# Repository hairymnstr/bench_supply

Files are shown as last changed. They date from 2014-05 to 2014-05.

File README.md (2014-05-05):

Bench Supply
============

This is a fairly basic bench power supply project I'm working on.  It started
off as a one-off design with all through-hole and stripboard construction but
I'm probably going to get the channels at least done on a PCB to make it more
robust.

All done in KiCAD so far, there will be some software for driving the current
and voltage displays later on.  There are two projects so far, the control
board which is a one-off that does non channel specific things like output on
off control, and a channel design which I'm using twice to provide two
separate floating supply rails.

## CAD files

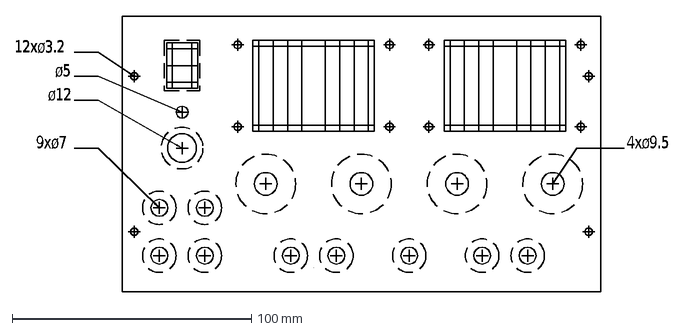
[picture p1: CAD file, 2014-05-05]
sch/channel/front_panel.dxf
12xø3.2
9xø7
ø12
ø5
4xø9.5

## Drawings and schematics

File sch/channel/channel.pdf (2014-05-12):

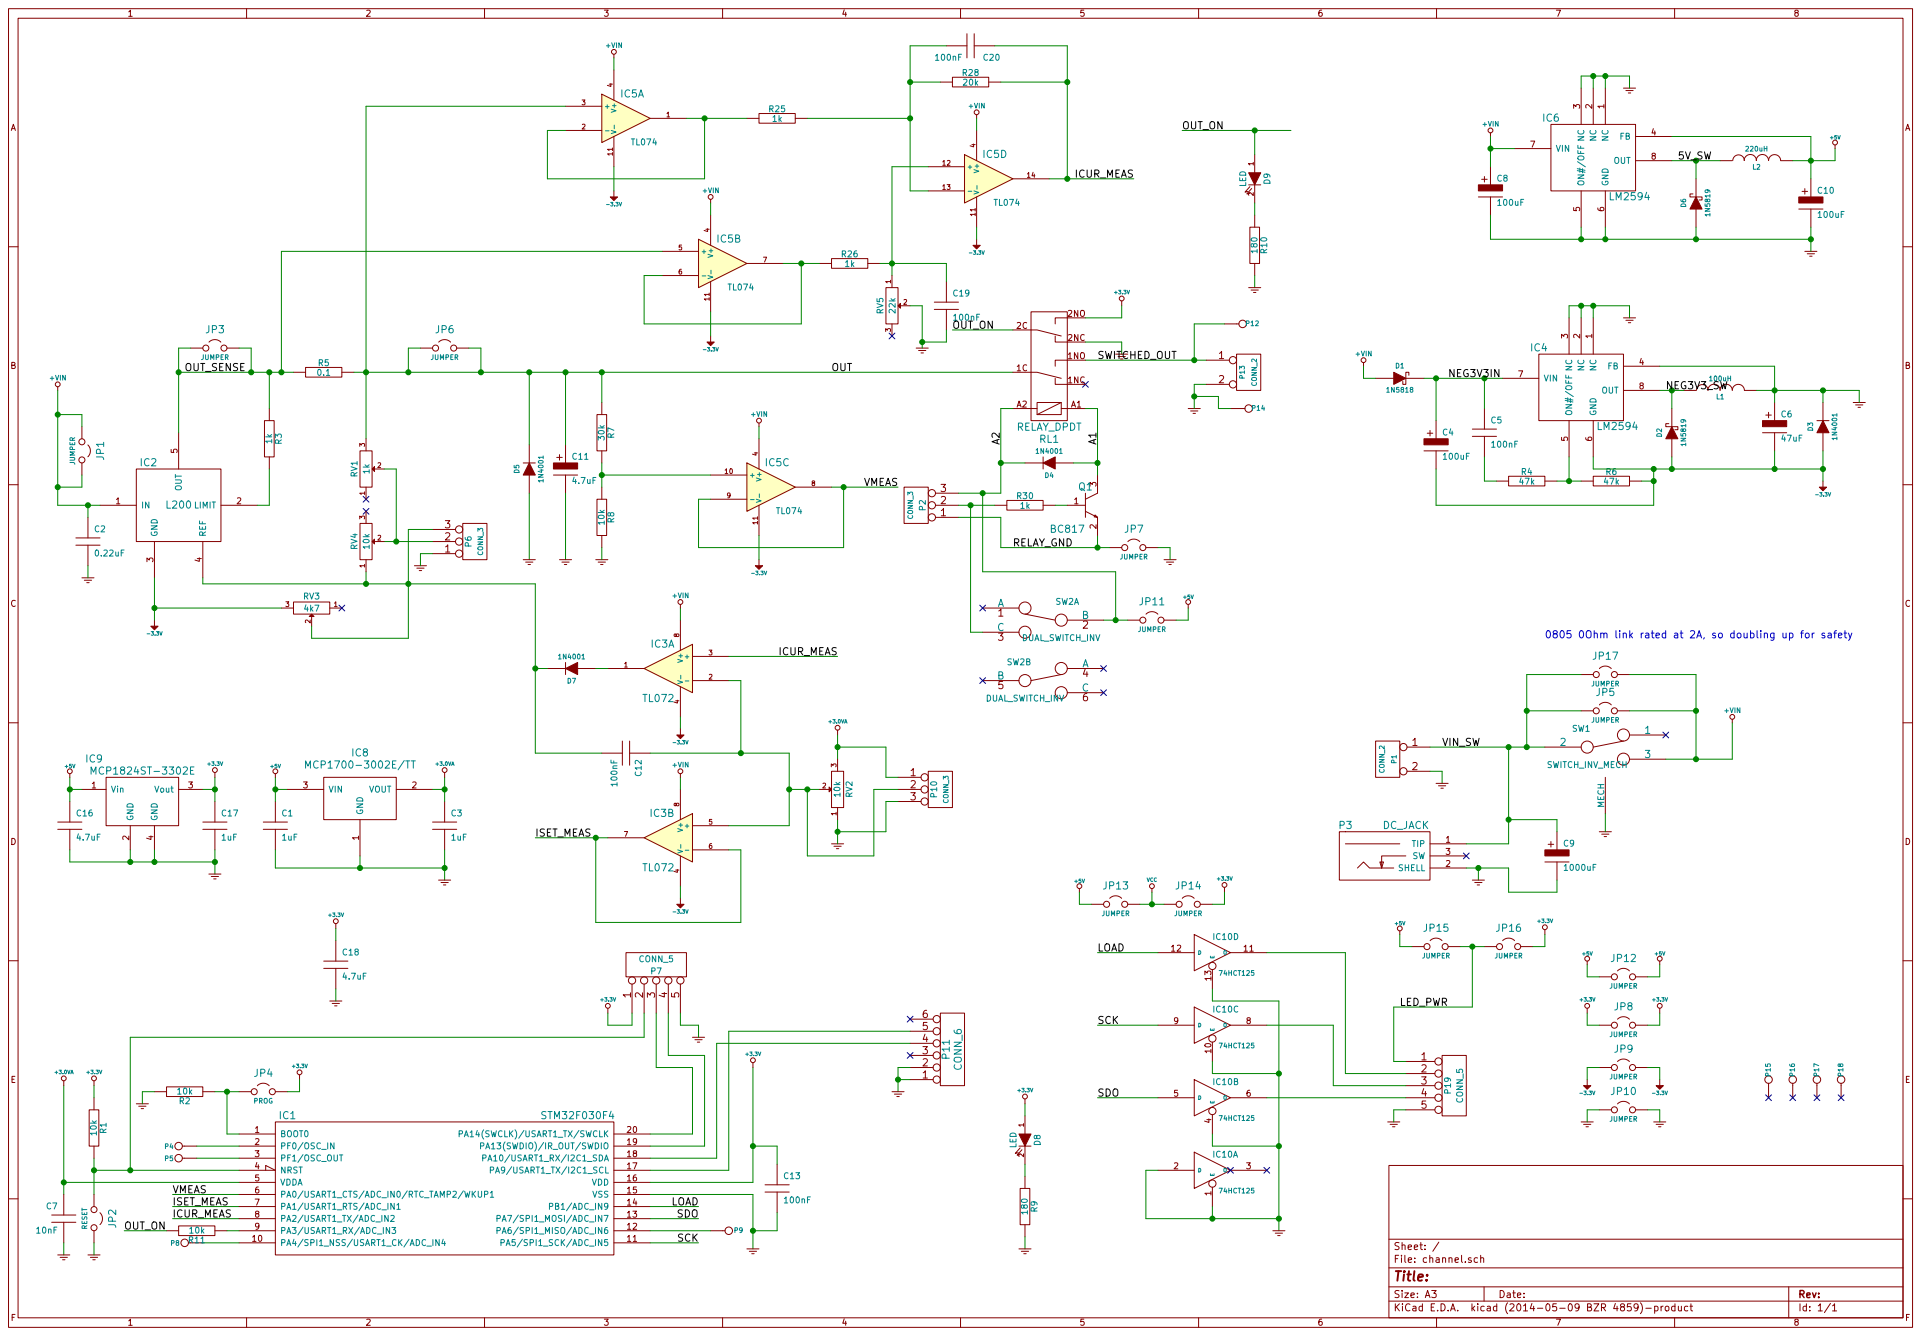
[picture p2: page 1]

JUMPER 0805 0Ohm link rated at 2A, so doubling up for safety

Id: 1/1 Title: File: channel.sch Sheet: / VMEAS

ISET_MEAS | | LOAD
ICUR_MEAS | SDO

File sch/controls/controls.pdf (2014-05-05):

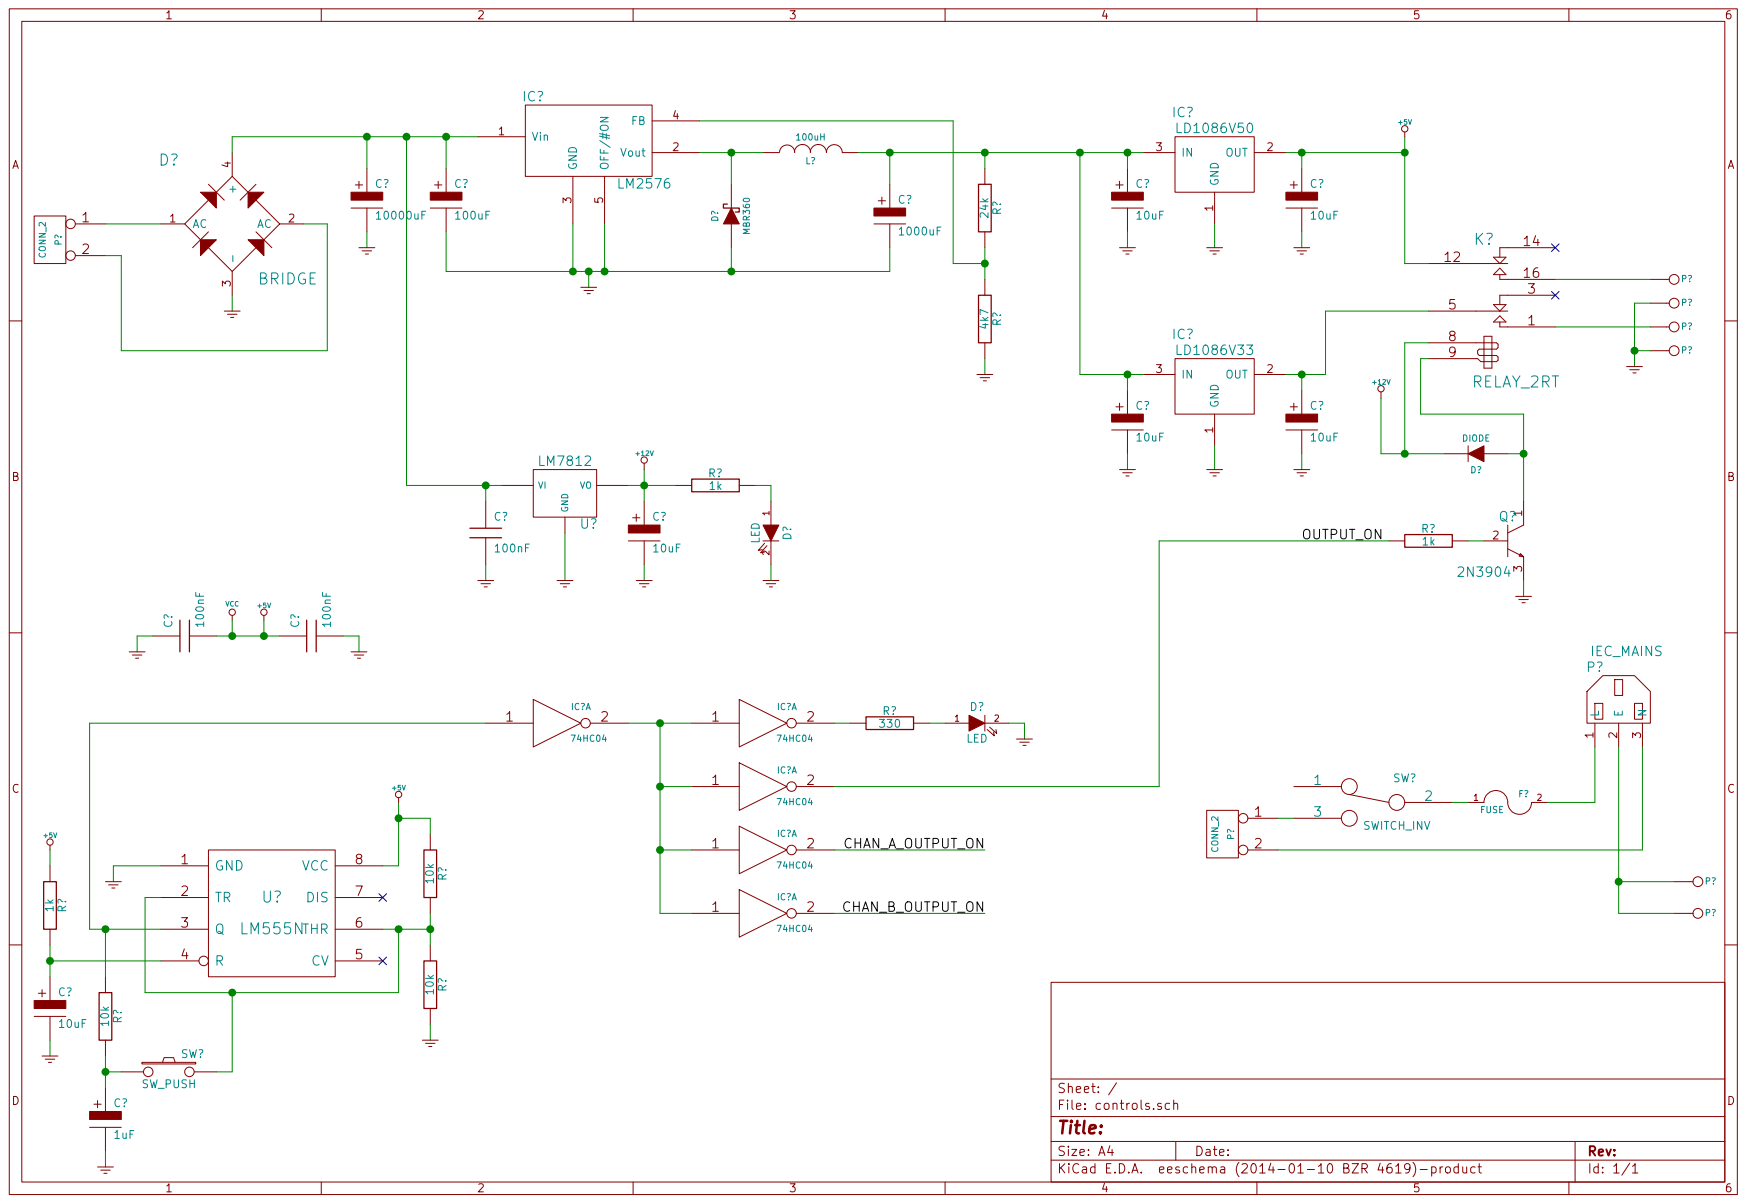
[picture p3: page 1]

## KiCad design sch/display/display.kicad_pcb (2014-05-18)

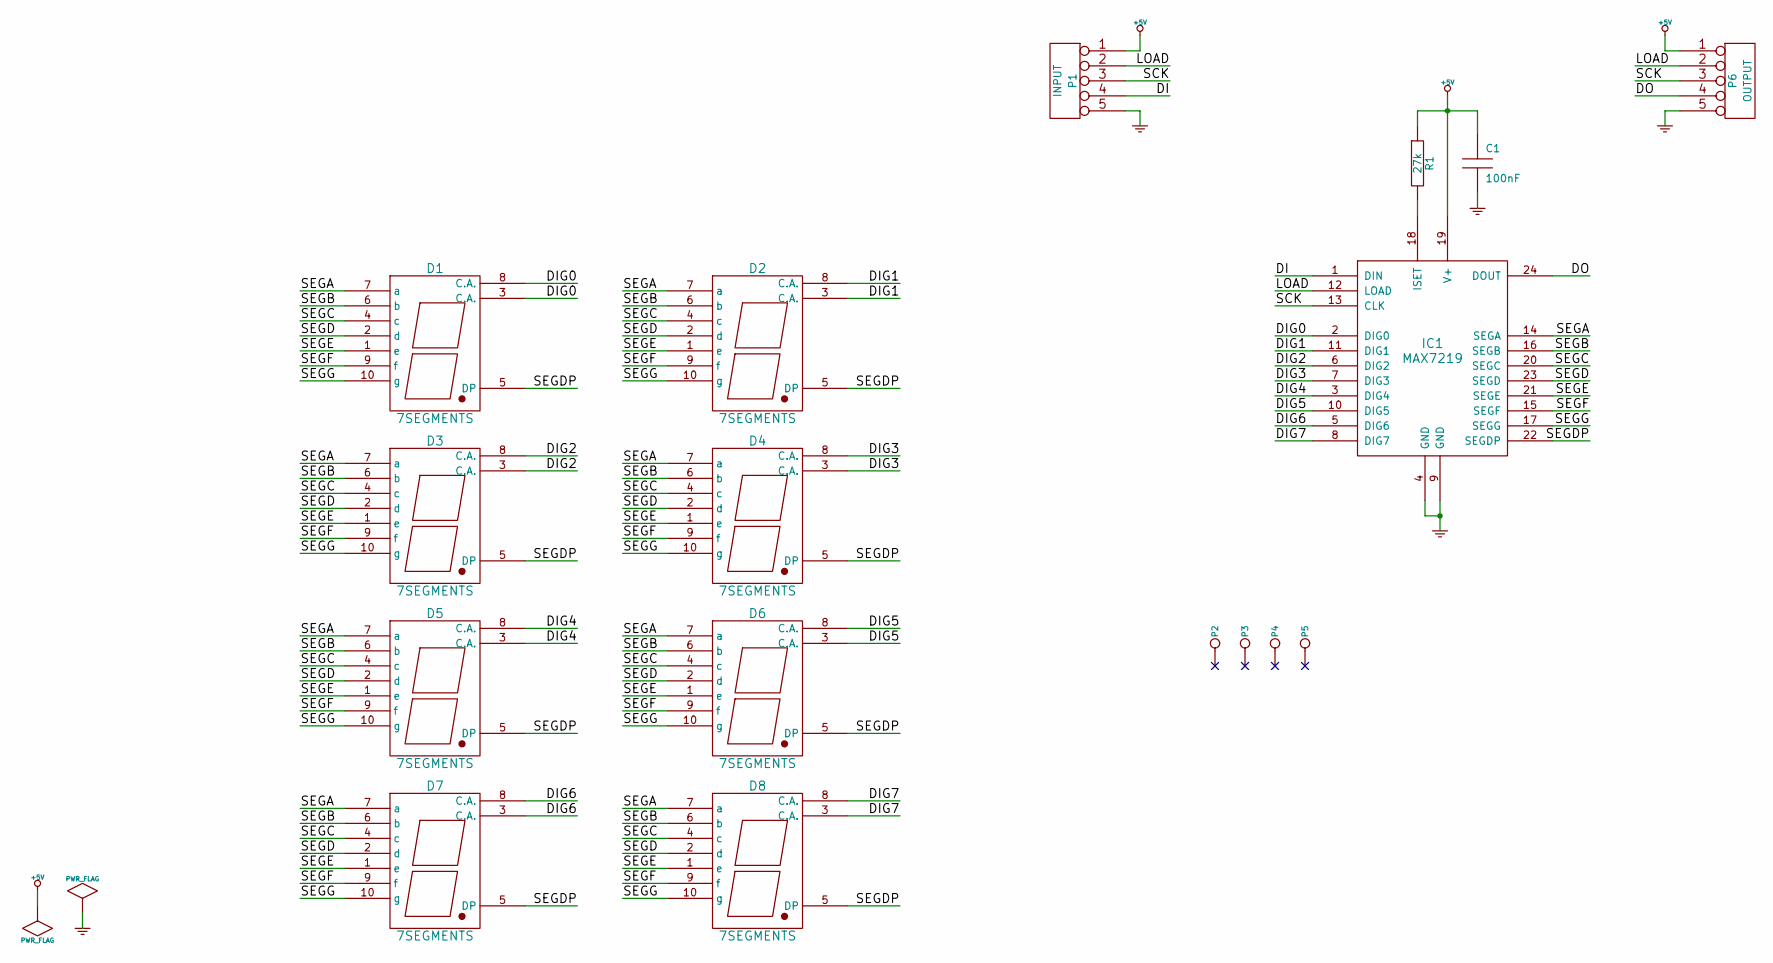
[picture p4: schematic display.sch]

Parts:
C1: 100nF
D1, D2, D3, D4, D5, D6, D7, D8: 7SEGMENTS
IC1: MAX7219
P1: INPUT
P2, P3, P4, P5: CONN_1
P6: OUTPUT
R1: 27k

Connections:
+5V: C1.1, IC1.19 (V+), P1.1, P6.1, R1.1
/DI: IC1.1 (DIN), P1.4
/DIG0: D1.3 (C.A.), D1.8 (C.A.), IC1.2 (DIG0)
/DIG1: D2.3 (C.A.), D2.8 (C.A.), IC1.11 (DIG1)
/DIG2: D3.3 (C.A.), D3.8 (C.A.), IC1.6 (DIG2)
/DIG3: D4.3 (C.A.), D4.8 (C.A.), IC1.7 (DIG3)
/DIG4: D5.3 (C.A.), D5.8 (C.A.), IC1.3 (DIG4)
/DIG5: D6.3 (C.A.), D6.8 (C.A.), IC1.10 (DIG5)
/DIG6: D7.3 (C.A.), D7.8 (C.A.), IC1.5 (DIG6)
/DIG7: D8.3 (C.A.), D8.8 (C.A.), IC1.8 (DIG7)
/DO: IC1.24 (DOUT), P6.4
/LOAD: IC1.12 (LOAD), P1.2, P6.2
/SCK: IC1.13 (CLK), P1.3, P6.3
/SEGA: D1.7 (a), D2.7 (a), D3.7 (a), D4.7 (a), D5.7 (a), D6.7 (a), D7.7 (a), D8.7 (a), IC1.14 (SEGA)
/SEGB: D1.6 (b), D2.6 (b), D3.6 (b), D4.6 (b), D5.6 (b), D6.6 (b), D7.6 (b), D8.6 (b), IC1.16 (SEGB)
/SEGC: D1.4 (c), D2.4 (c), D3.4 (c), D4.4 (c), D5.4 (c), D6.4 (c), D7.4 (c), D8.4 (c), IC1.20 (SEGC)
/SEGD: D1.2 (d), D2.2 (d), D3.2 (d), D4.2 (d), D5.2 (d), D6.2 (d), D7.2 (d), D8.2 (d), IC1.23 (SEGD)
/SEGDP: D1.5 (DP), D2.5 (DP), D3.5 (DP), D4.5 (DP), D5.5 (DP), D6.5 (DP), D7.5 (DP), D8.5 (DP), IC1.22 (SEGDP)
/SEGE: D1.1 (e), D2.1 (e), D3.1 (e), D4.1 (e), D5.1 (e), D6.1 (e), D7.1 (e), D8.1 (e), IC1.21 (SEGE)
/SEGF: D1.9 (f), D2.9 (f), D3.9 (f), D4.9 (f), D5.9 (f), D6.9 (f), D7.9 (f), D8.9 (f), IC1.15 (SEGF)
/SEGG: D1.10 (g), D2.10 (g), D3.10 (g), D4.10 (g), D5.10 (g), D6.10 (g), D7.10 (g), D8.10 (g), IC1.17 (SEGG)
GND: C1.2, IC1.4 (GND), IC1.9 (GND), P1.5, P6.5
unnamed: IC1.18 (ISET), R1.2

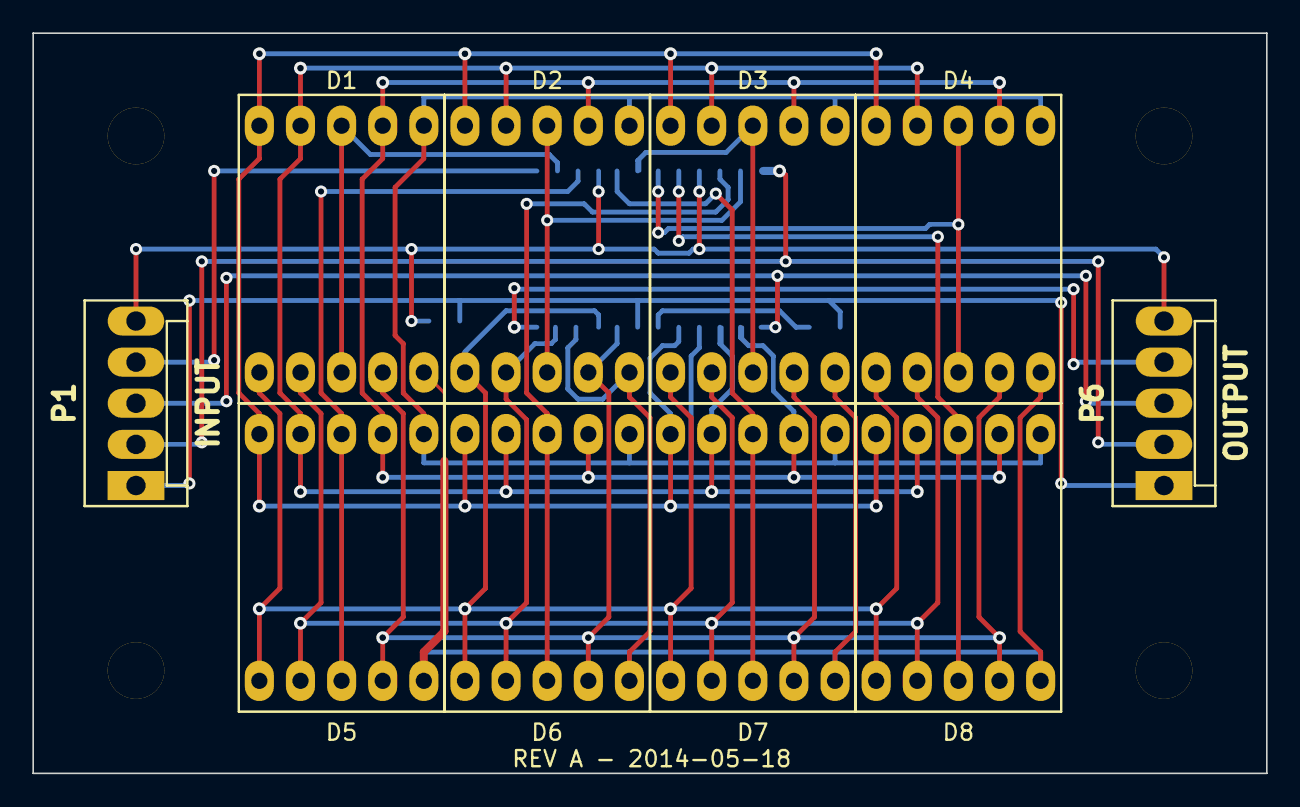
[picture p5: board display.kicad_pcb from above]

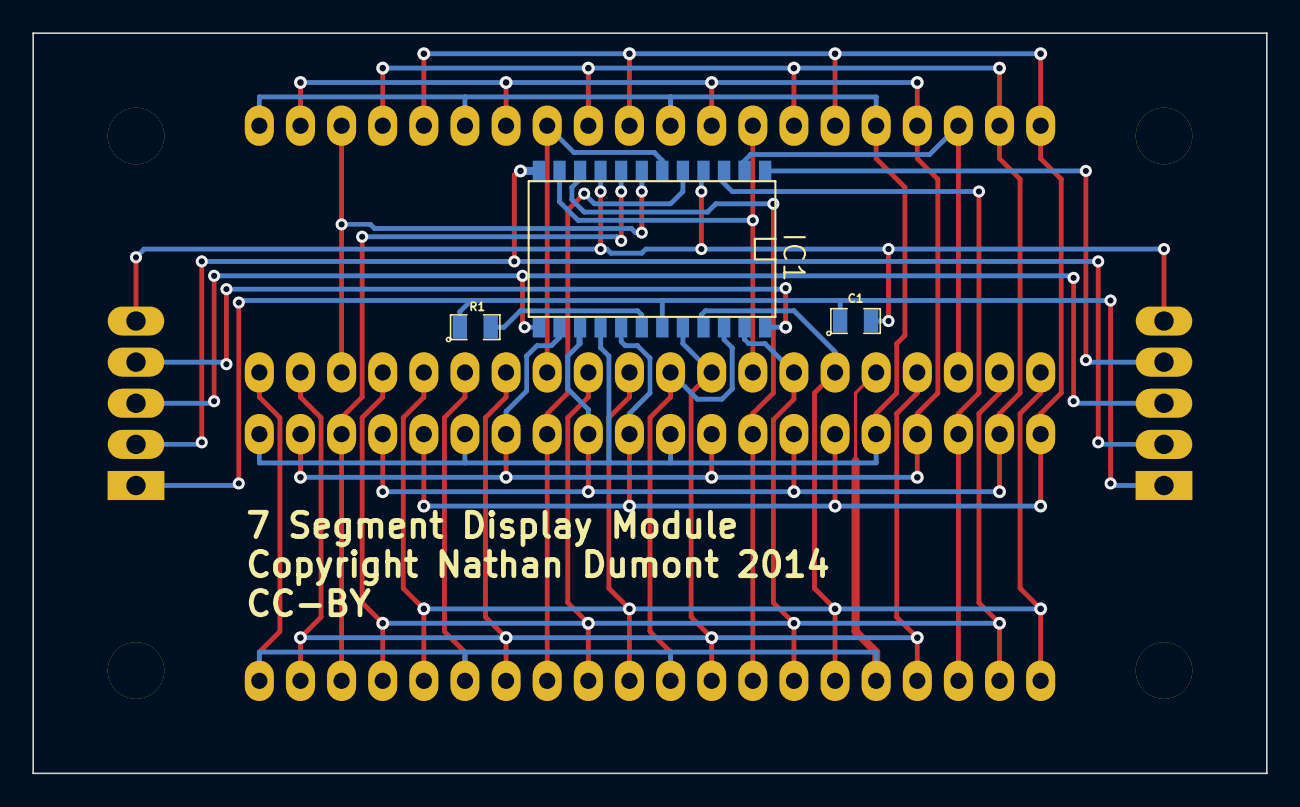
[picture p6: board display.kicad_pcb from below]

Board: 2 copper layers, 76.2 x 45.7 mm, 17 parts (3 on the bottom side), 23 nets.

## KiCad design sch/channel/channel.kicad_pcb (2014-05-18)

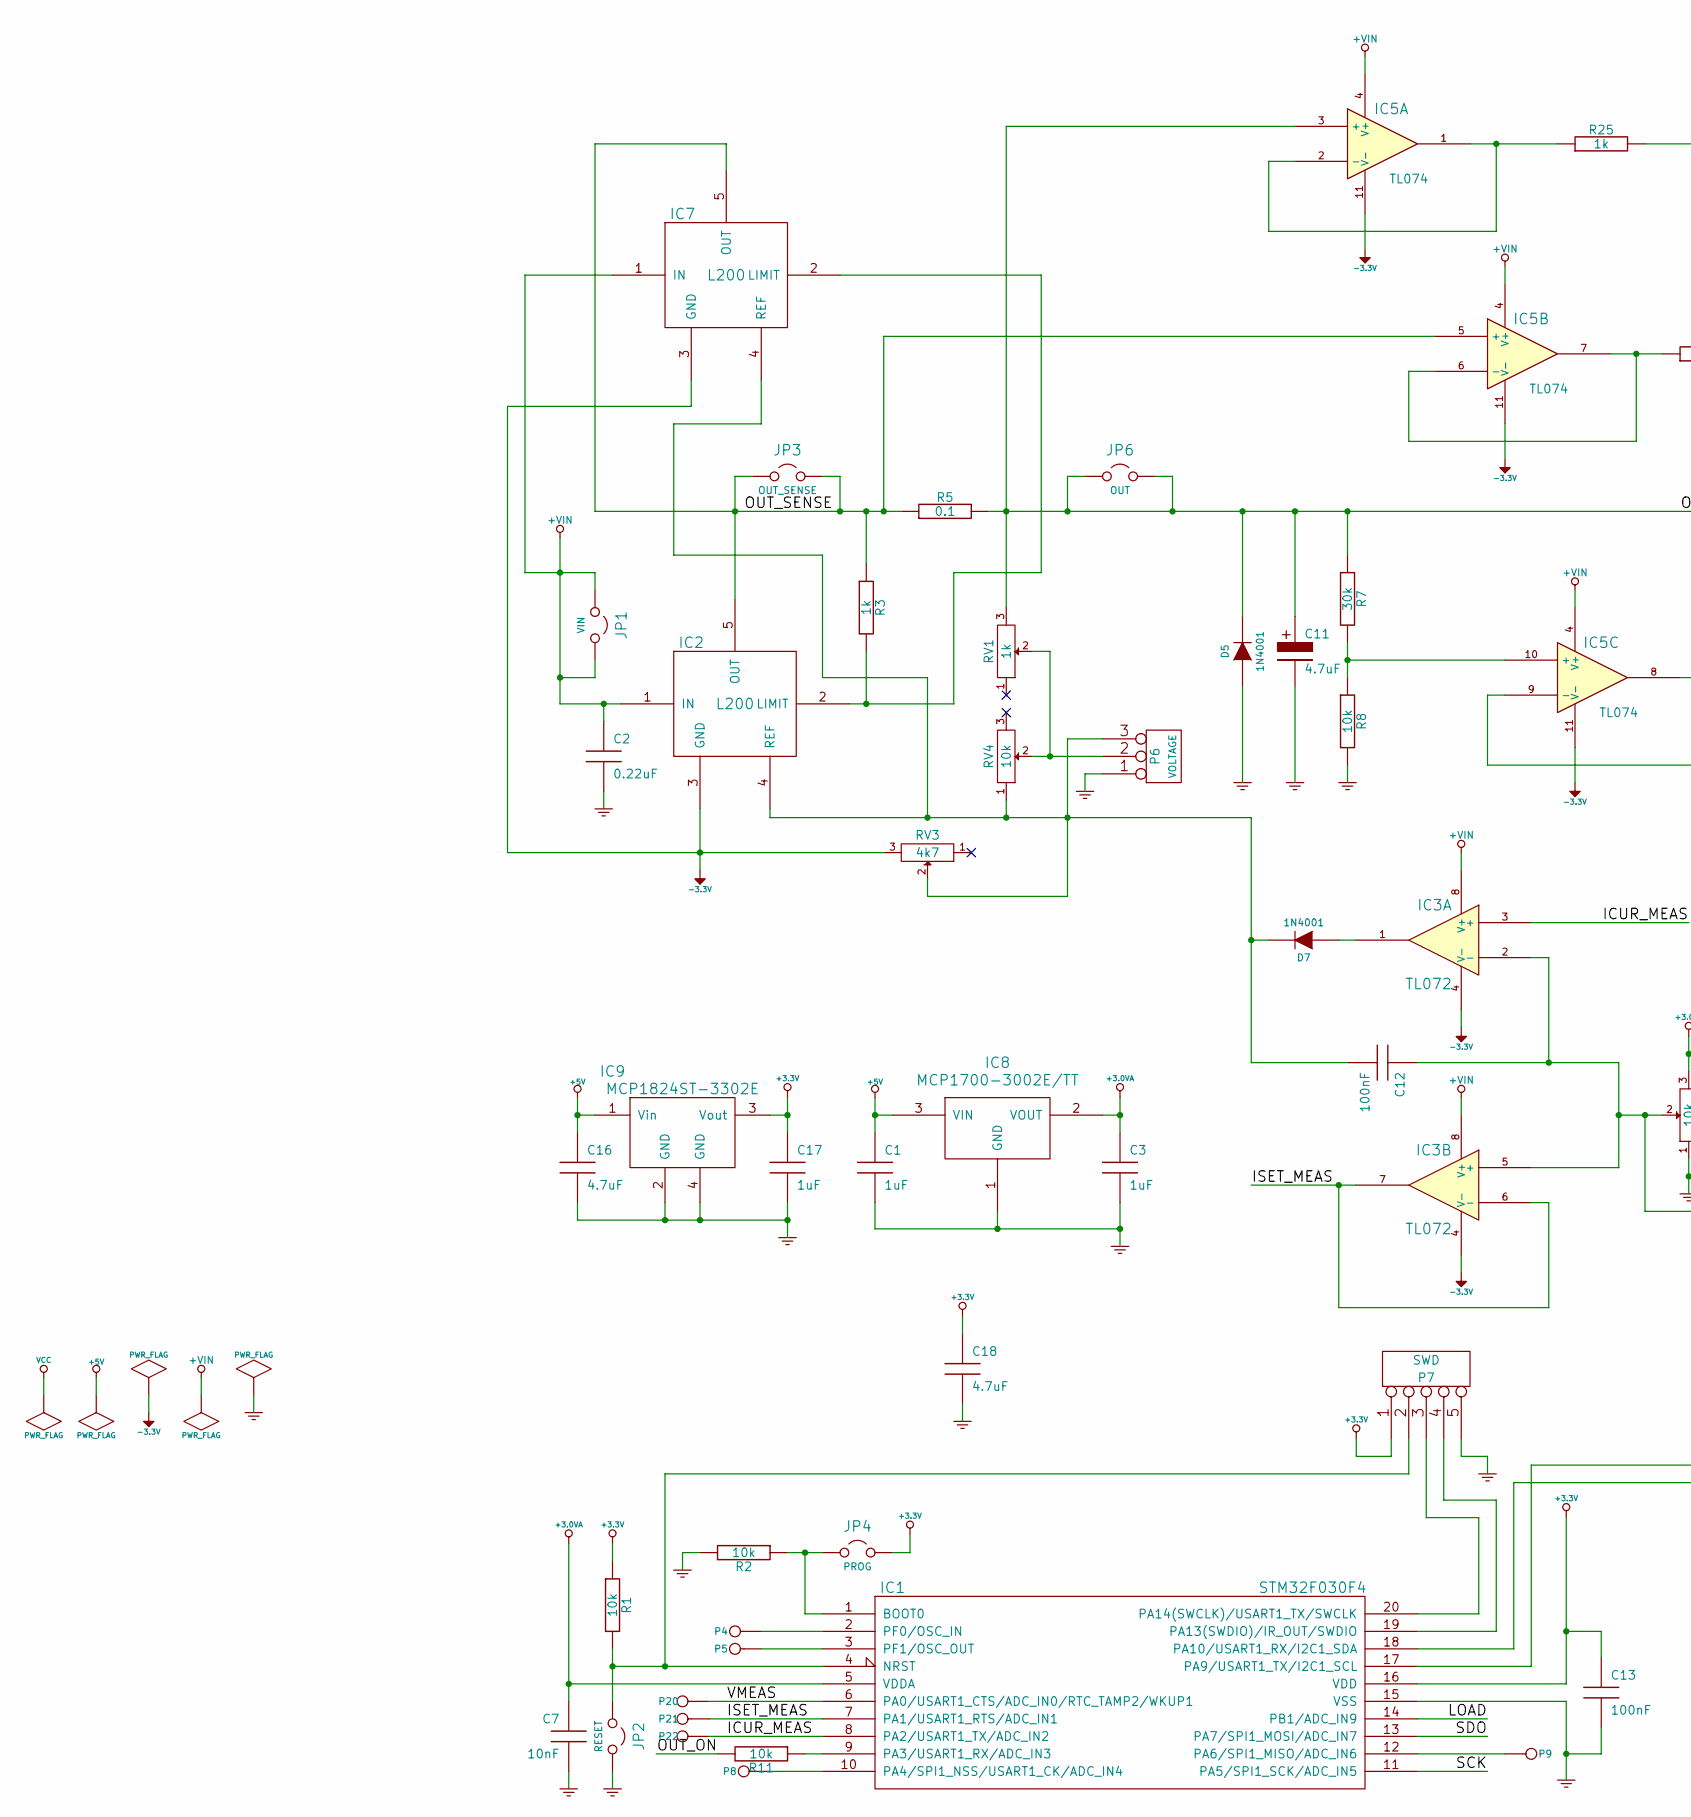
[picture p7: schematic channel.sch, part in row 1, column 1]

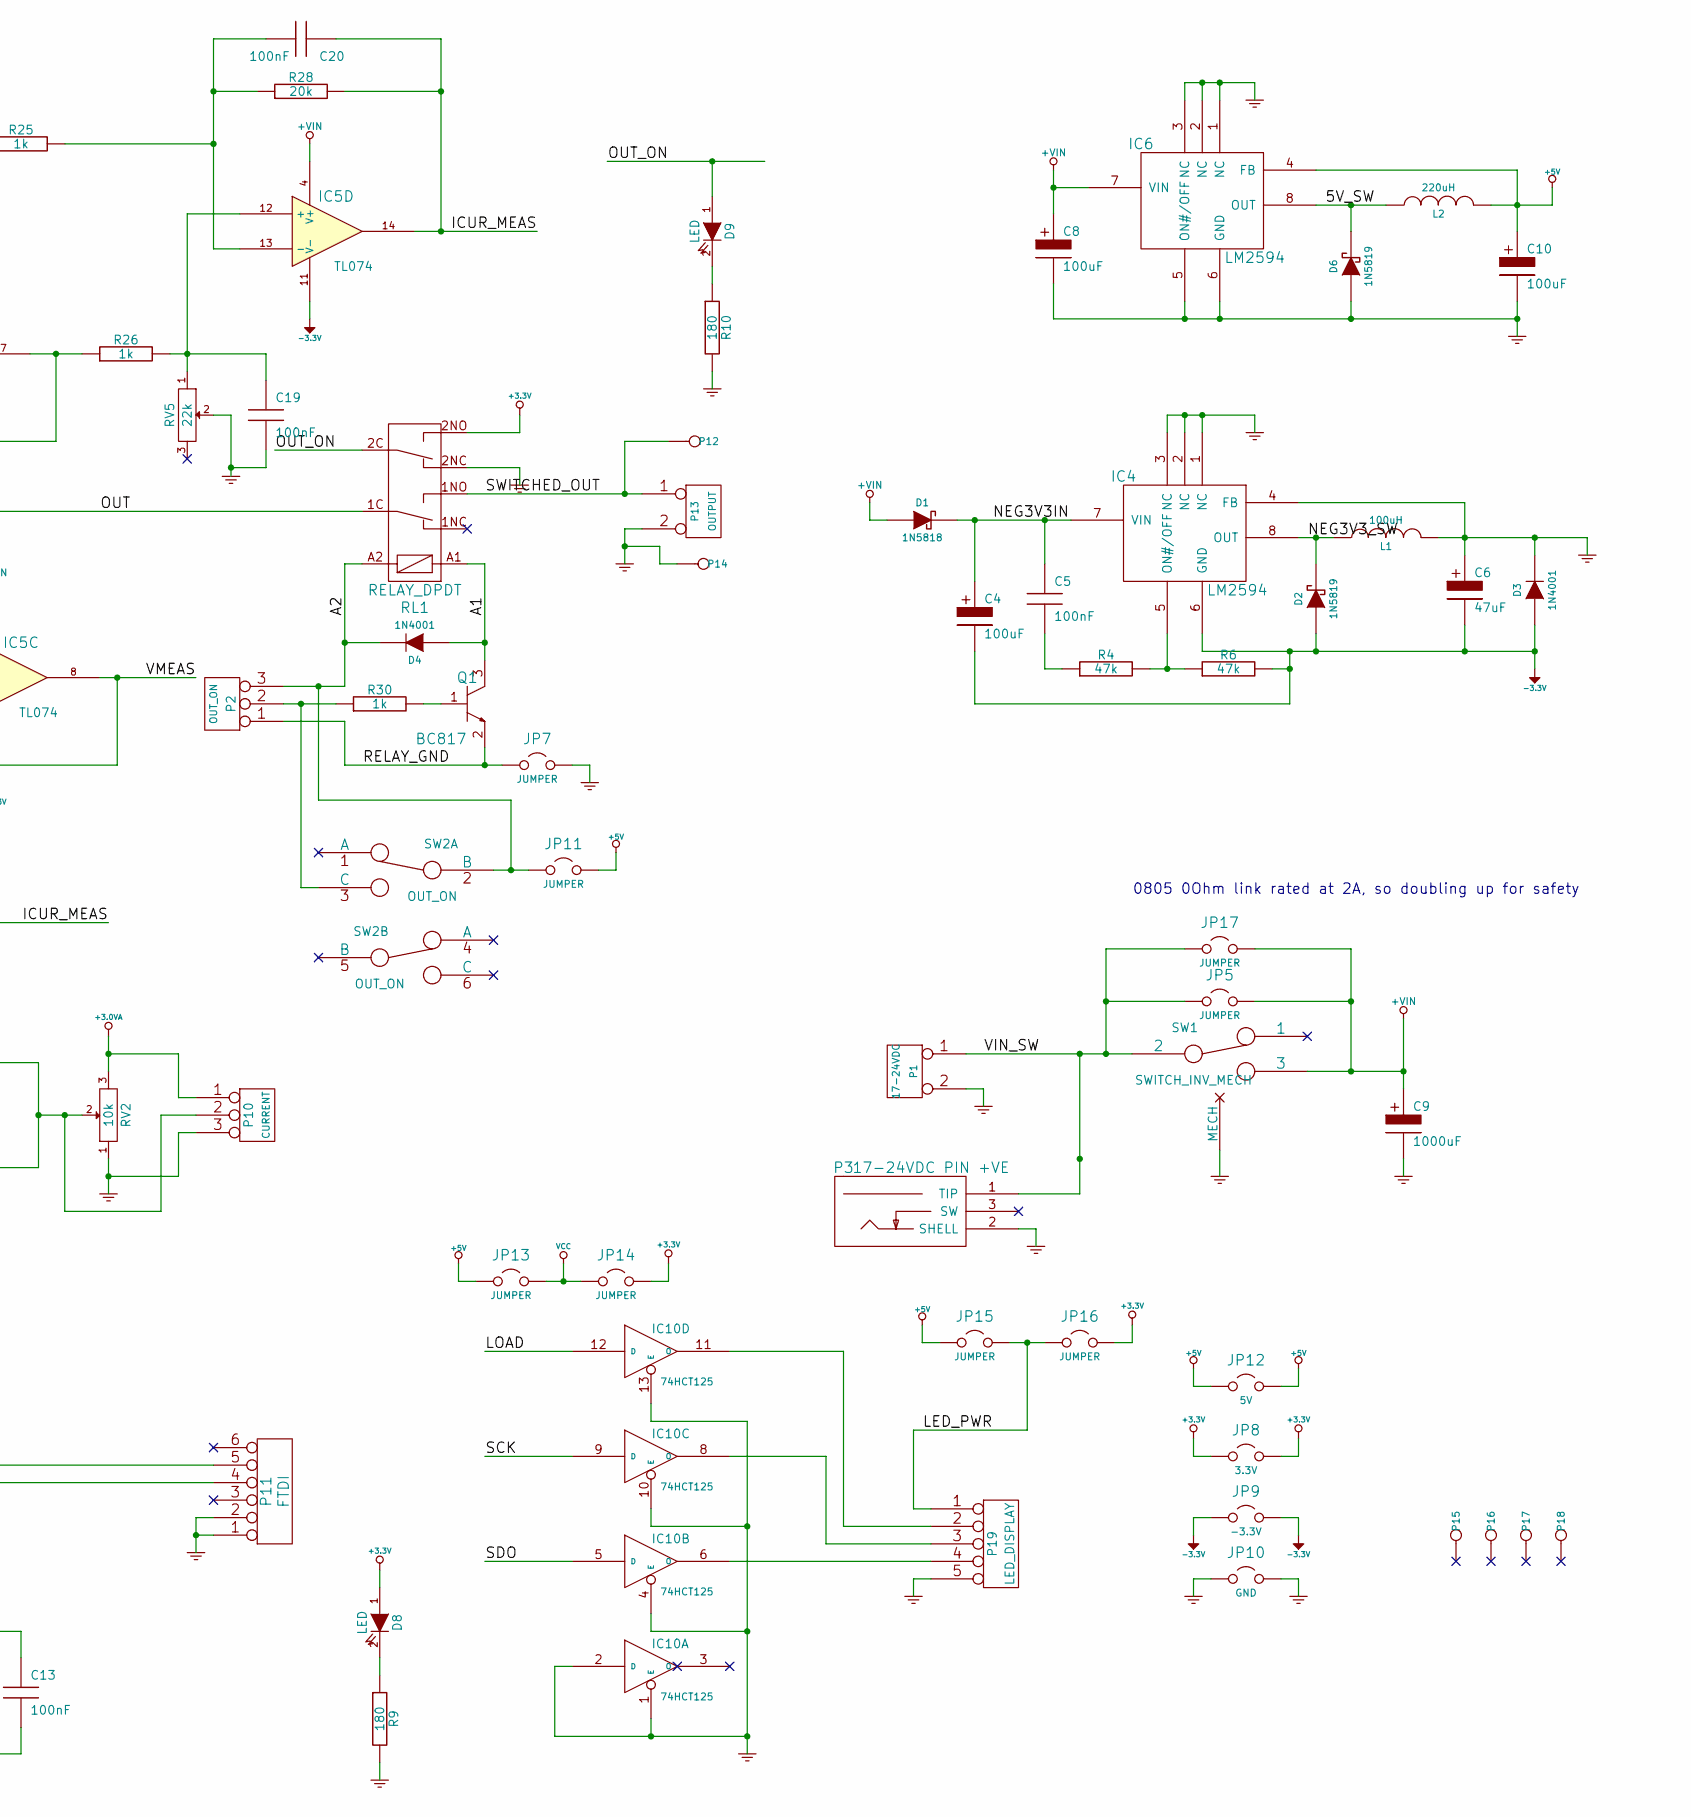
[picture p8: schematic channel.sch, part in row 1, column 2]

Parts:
C1, C3, C17: 1uF
C2: 0.22uF
C4, C8, C10: 100uF
C5, C12, C13, C19, C20: 100nF
C6: 47uF
C7: 10nF
C9: 1000uF
C11, C16, C18: 4.7uF
D1: 1N5818
D2, D6: 1N5819
D3, D4, D5, D7: 1N4001
D8, D9: LED
IC1: STM32F030F4
IC2, IC7: L200
IC3: TL072; Farnell 156-4343
IC4, IC6: LM2594
IC5: TL074; Farnell 959-3349
IC8: MCP1700-3002E/TT
IC9: MCP1824ST-3302E
IC10: 74HCT125; Farnell 120-1306
JP1: VIN
JP2: RESET
JP3: OUT_SENSE
JP4: PROG
JP5, JP7, JP11, JP13, JP14, JP15, JP16, JP17: JUMPER
JP6: OUT
JP8: 3.3V
JP9: -3.3V
JP10: GND
JP12: 5V
L1: 100uH
L2: 220uH
P1: 17-24VDC
P2: OUT_ON
P3: 17-24VDC PIN +VE
P4, P5, P8, P9, P12, P14, P15, P16, P17, P18: CONN_1
P6: VOLTAGE
P7: SWD
P10: CURRENT
P11: FTDI
P13: OUTPUT
P19: LED_DISPLAY
P20: V
P21: I_SET
P22: I_NOW
Q1: BC817
R1, R2, R8, R11: 10k
R3, R25, R26, R30: 1k
R4, R6: 47k
R5: 0.1
R7: 30k
R9, R10: 180
R28: 20k
RL1: RELAY_DPDT
RV1: 1k
RV2, RV4: 10k
RV3: 4k7
RV5: 22k
SW1: SWITCH_INV_MECH
SW2: OUT_ON

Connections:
+3.0VA: C3.1, C7.1, IC1.5 (VDDA), IC8.2 (VOUT), P10.1, RV2.3
+3.3V: C13.1, C17.1, C18.1, D8.1 (A), IC1.16 (VDD), IC9.3 (Vout), JP4.2, JP8.1, JP8.2, JP14.2, JP16.2, P7.1, R1.1, RL1.2NO
+5V: C1.1, C10.1, C16.1, IC6.4 (FB), IC8.3 (VIN), IC9.1 (Vin), JP11.2, JP12.1, JP12.2, JP13.1, JP15.1, L2.2
+VIN: C2.1, C8.1, C9.1, D1.1 (A), IC2.1 (IN), IC3.8 (V+), IC5.4 (V+), IC6.7 (VIN), IC7.1 (IN), JP1.1, JP1.2, JP5.2, JP17.2, SW1.3
-3.3V: C4.2, C6.2, D2.1 (A), D3.1 (A), IC2.3 (GND), IC3.4 (V-), IC4.6 (GND), IC5.11 (V-), IC7.3 (GND), JP9.1, JP9.2, R6.2, RV3.3
/5V_SW: D6.2 (K), IC6.8 (OUT), L2.1
/A1: D4.1 (A), Q1.3 (C), RL1.A1
/A2: D4.2 (K), JP11.1, P2.3, RL1.A2, SW2.2 (B)
/ICUR_MEAS: C20.1, IC1.8 (PA2/USART1_TX/ADC_IN2), IC3.3 (+), IC5.14, P22.1, R28.2
/ISET_MEAS: IC1.7 (PA1/USART1_RTS/ADC_IN1), IC3.6 (-), IC3.7, P21.1
/LED_PWR: JP15.2, JP16.1, P19.1
/LOAD: IC1.14 (PB1/ADC_IN9), IC10.12 (D)
/NEG3V3IN: C4.1, C5.1, D1.2 (K), IC4.7 (VIN)
/NEG3V3_SW: D2.2 (K), IC4.8 (OUT), L1.1
/OUT: C11.1, D5.2 (K), IC5.3 (+), JP6.1, JP6.2, R5.2, R7.1, RL1.1C, RV1.3
/OUT_ON: D9.1 (A), R11.2, RL1.2C
/OUT_SENSE: IC2.5 (OUT), IC5.5 (+), IC7.5 (OUT), JP3.1, JP3.2, R3.1, R5.1
/RELAY_GND: JP7.1, P2.1, Q1.2 (E)
/SCK: IC1.11 (PA5/SPI1_SCK/ADC_IN5), IC10.9 (D)
/SDO: IC1.13 (PA7/SPI1_MOSI/ADC_IN7), IC10.5 (D)
/SWITCHED_OUT: P12.1, P13.1, RL1.1NO
/VIN_SW: JP5.1, JP17.1, P1.1, P3.1 (TIP), SW1.2
/VMEAS: IC1.6 (PA0/USART1_CTS/ADC_IN0/RTC_TAMP2/WKUP1), IC5.8, IC5.9 (-), P20.1
GND: C1.2, C2.2, C3.2, C6.1, C7.2, C8.2, C9.2, C10.2, C11.2, C13.2, C16.2, C17.2, C18.2, C19.2, D3.2 (K), D5.1 (A), D6.1 (A), IC1.15 (VSS), IC4.1 (NC), IC4.2 (NC), IC4.3 (NC), IC4.4 (FB), IC6.1 (NC), IC6.2 (NC), IC6.3 (NC), IC6.5 (ON#/OFF), IC6.6 (GND), IC8.1 (GND), IC9.2 (GND), IC9.4 (GND), IC10.1 (E), IC10.2 (D), IC10.4 (E), IC10.7 (GND), IC10.10 (E), IC10.13 (E), JP2.2, JP7.2, JP10.1, JP10.2, L1.2, P1.2 (PM), P3.2 (SHELL), P6.1, P7.5, P10.3, P11.1, P11.2, P13.2 (PM), P14.1, P19.5, R2.2, R8.2, R9.2, R10.2, RL1.2NC, RV2.1, RV2.GND, RV4.GND, RV5.2, SW1.4 (MECH)
unnamed: C5.2, R4.1
unnamed: C12.1, IC3.2 (-), IC3.5 (+), P10.2 (PM), RV2.2
unnamed: C12.2, D7.2 (K), IC2.4 (REF), IC7.4 (REF), P6.3, RV3.2, RV4.1
unnamed: C19.1, IC5.12 (+), R26.2, RV5.1
unnamed: C20.2, IC5.13 (-), R25.2, R28.1
unnamed: D7.1 (A), IC3.1
unnamed: D8.2 (K), R9.1
unnamed: D9.2 (K), R10.1
unnamed: IC1.1 (BOOT0), JP4.1, R2.1
unnamed: IC1.2 (PF0/OSC_IN), P4.1
unnamed: IC1.3 (PF1/OSC_OUT), P5.1
unnamed: IC1.4 (NRST), JP2.1, P7.2, R1.2
unnamed: IC1.9 (PA3/USART1_RX/ADC_IN3), R11.1
unnamed: IC1.10 (PA4/SPI1_NSS/USART1_CK/ADC_IN4), P8.1
unnamed: IC1.12 (PA6/SPI1_MISO/ADC_IN6), P9.1
unnamed: IC1.17 (PA9/USART1_TX/I2C1_SCL), P11.5
unnamed: IC1.18 (PA10/USART1_RX/I2C1_SDA), P11.4
unnamed: IC1.19 (PA13(SWDIO)/IR_OUT/SWDIO), P7.4
unnamed: IC1.20 (PA14(SWCLK)/USART1_TX/SWCLK), P7.3
unnamed: IC2.2 (LIMIT), IC7.2 (LIMIT), R3.2
unnamed: IC4.5 (ON#/OFF), R4.2, R6.1
unnamed: IC5.1, IC5.2 (-), R25.1
unnamed: IC5.6 (-), IC5.7, R26.1
unnamed: IC5.10 (+), R7.2, R8.1
unnamed: IC10.6 (O), P19.4
unnamed: IC10.8 (O), P19.3
unnamed: IC10.11 (O), P19.2
unnamed: P2.2 (PM), R30.1, SW2.3 (C)
unnamed: P6.2 (PM), RV1.2, RV4.2
unnamed: Q1.1 (B), R30.2
VCC: IC10.14 (VCC), JP13.2, JP14.1

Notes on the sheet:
0805 0Ohm link rated at 2A, so doubling up for safety

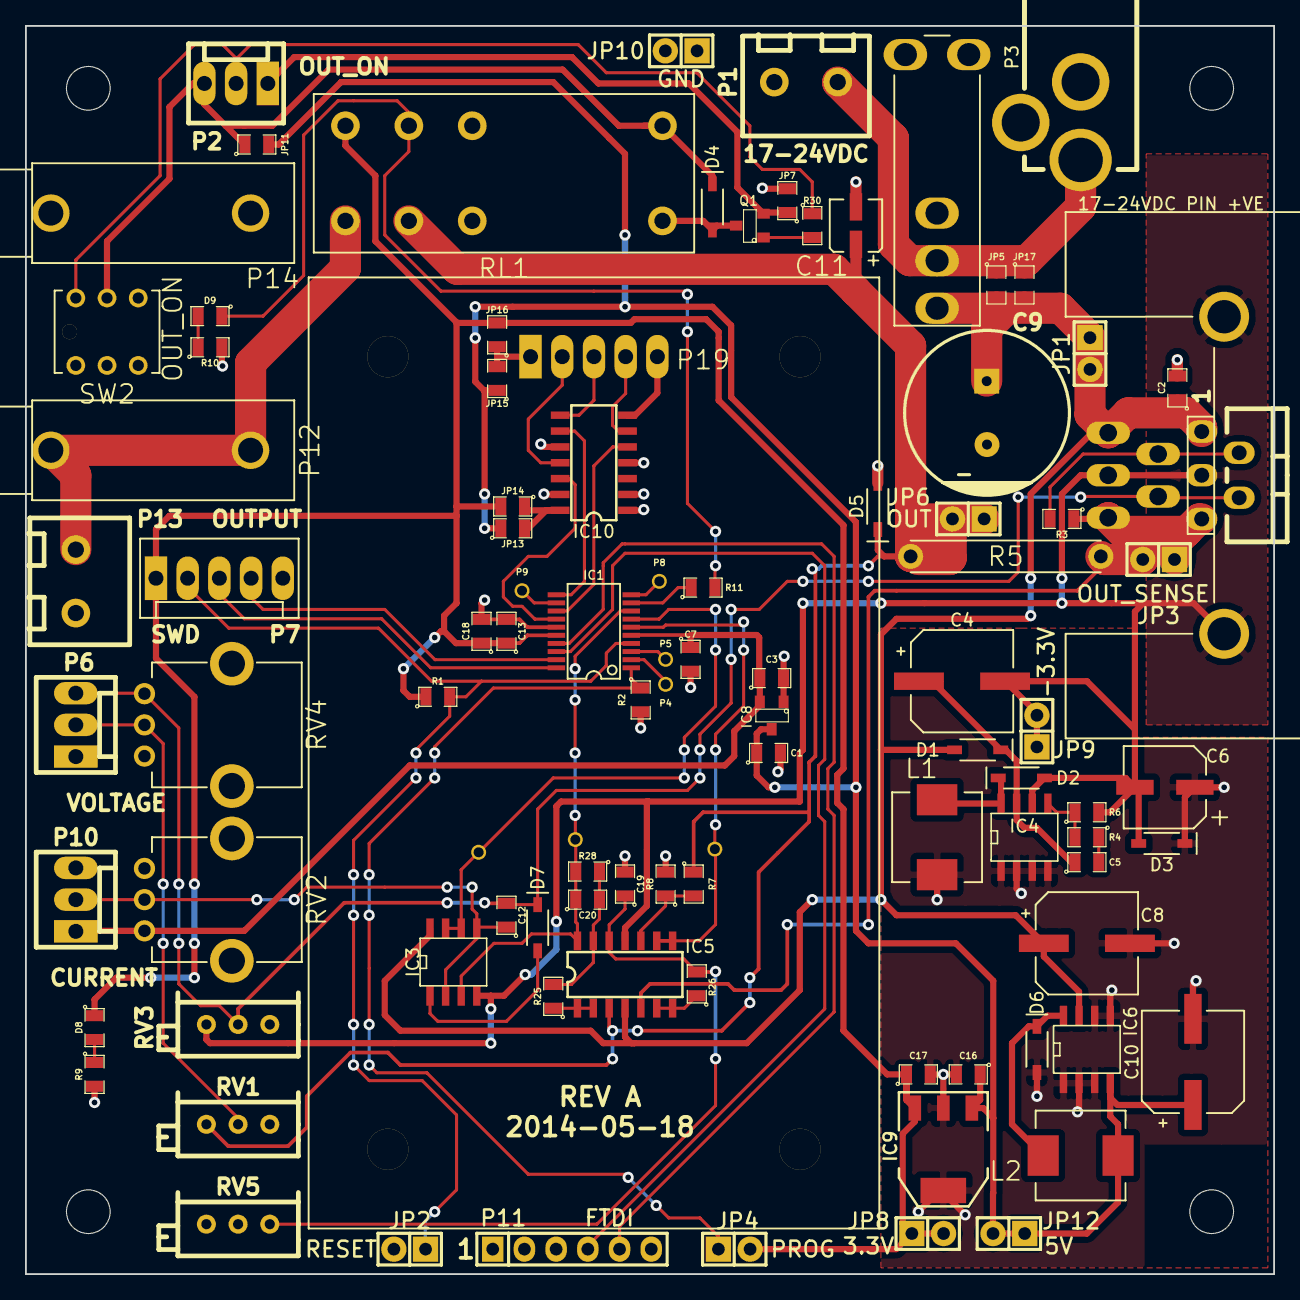
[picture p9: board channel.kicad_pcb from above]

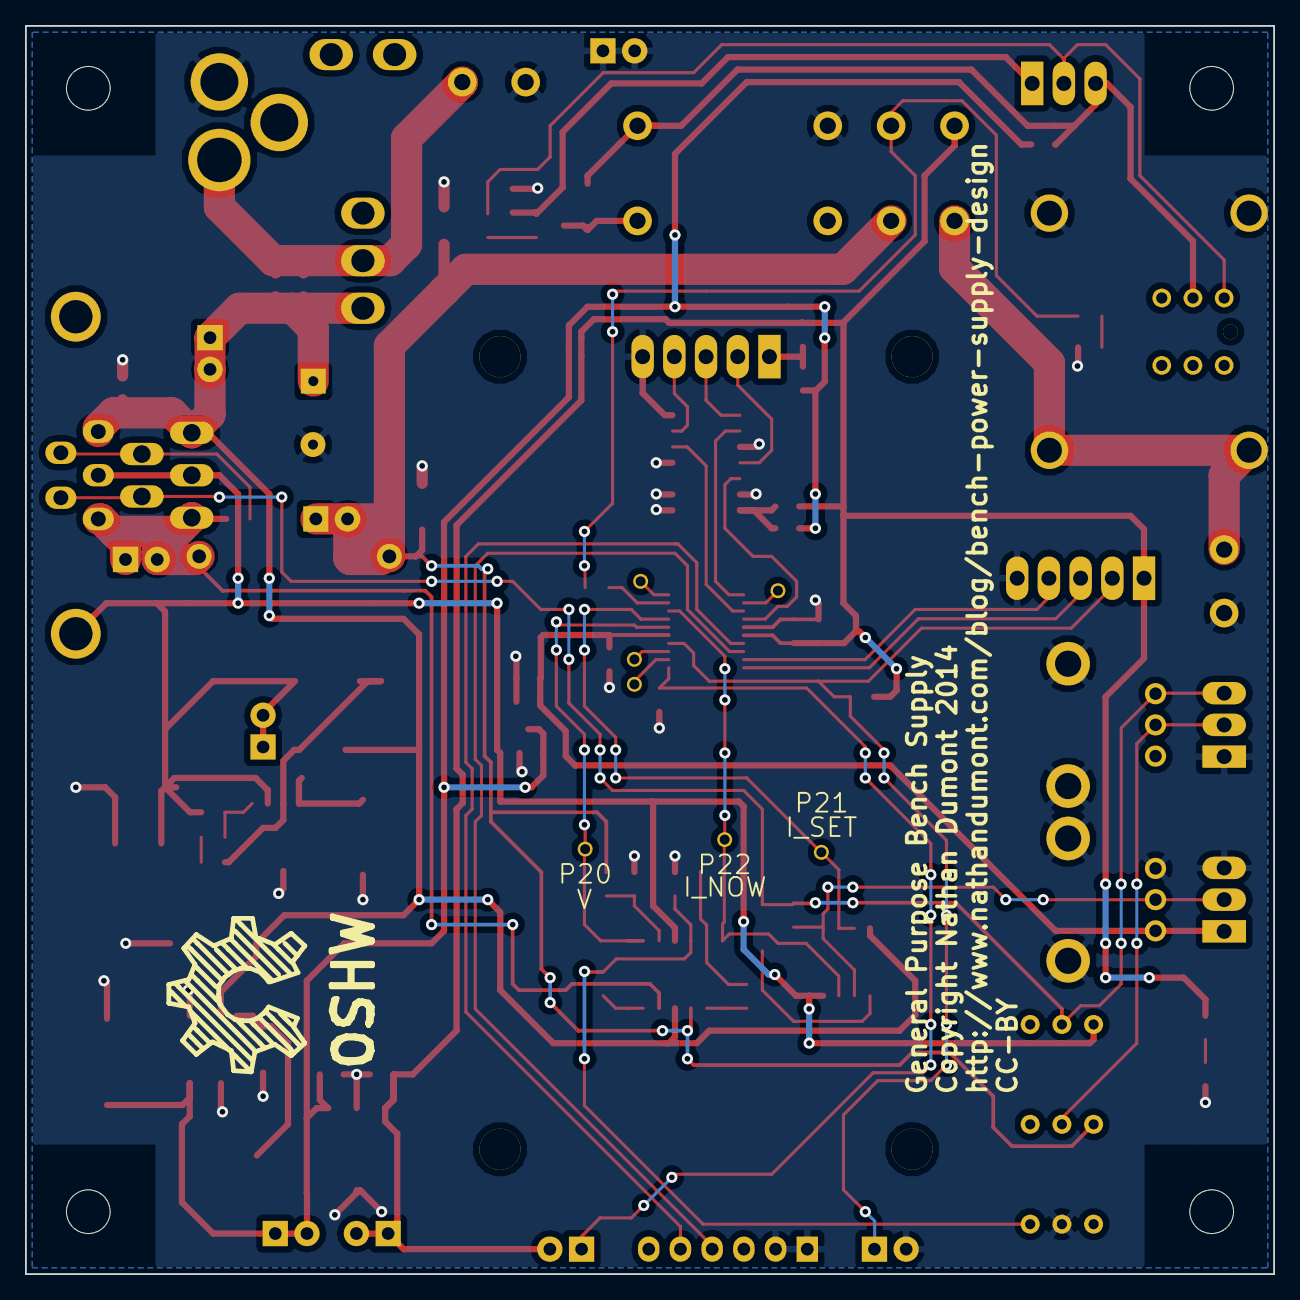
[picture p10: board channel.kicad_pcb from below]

Board: 2 copper layers, 100.0 x 100.0 mm, 103 parts (4 on the bottom side), 55 nets.

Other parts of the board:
Sym: Symbol_OSHW-Logo_SilkScreen_BIG_07Jul2012; Symbol_OSHW-Logo_SilkScreen_BIG

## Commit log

2014-05-05 Initial commit.
    [$noname.sch, controls.sch, front_panel.dxf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]
2014-05-05 Updated the channel schematic to new design. Ready to start on footprint assignment.
    [channel.sch, small_psu.sch]
2014-05-07 Started assigning footprints for components
    [channel.sch]
2014-05-09 Associating some more footprints
    [channel.sch]
2014-05-10 More footprints associated. Not done yet :(
2014-05-10 Fully assigned components, changed the design to remove opto-coupler, using relay instead
    [channel.sch]
2014-05-11 Fully laid out PCB. Needs a bit of tweaking for optimisation, and silk screen isn't done yet.
    [channel.kicad_pcb, channel.sch]
2014-05-11 A few tweaks to improve the layout. Still not sorted silk screen.
    [channel.kicad_pcb, channel.sch]
2014-05-12 Started designing the display board
    [display.sch]
2014-05-13 Started laying out the LED carrier PCB
    [display.kicad_pcb]
2014-05-15 Finished layout of the display. Not really happy with it though.
    [display.kicad_pcb]
2014-05-17 Fiddling with the layout of the display to make it more elegant.
    [display.kicad_pcb]
2014-05-17 Happy with the display module now. Not done gerbers/drill yet but layout is done incl. silk screen.
    [display.kicad_pcb, display.sch]
2014-05-17 Started ripping up the channel board to add a heatsink for standalone mode, and switch the display around so it faces the right way.
    [channel.kicad_pcb, channel.sch]
2014-05-17 More or less happy with the channel PCB. Needs silk screen sorting out.
    [channel.kicad_pcb, channel.sch]
2014-05-18 Final changes before ordering PCBs
    [channel.kicad_pcb, channel.sch, display.kicad_pcb]

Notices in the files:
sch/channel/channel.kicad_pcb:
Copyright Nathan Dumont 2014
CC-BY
